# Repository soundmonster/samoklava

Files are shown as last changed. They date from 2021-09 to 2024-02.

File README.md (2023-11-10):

# samoklava
## An autogenerated split 36 key keyboard

## Disclaimer

This is an early experimental prototype. Please do not rely on the autogenerated files and double check them manually
before sending them off to a PCB fab. The author and other random strangers on the internet have been able to produce
working keyboard prototypes from this repo; this does not mean that everything will work every time.

The author(s) waive(s) responsibility for any damage or regulatory violations caused by using this software (see
license). Please consult your local regulations around radio frequencies and what's allowed for DIY projects in your
country.

left | right
-|-
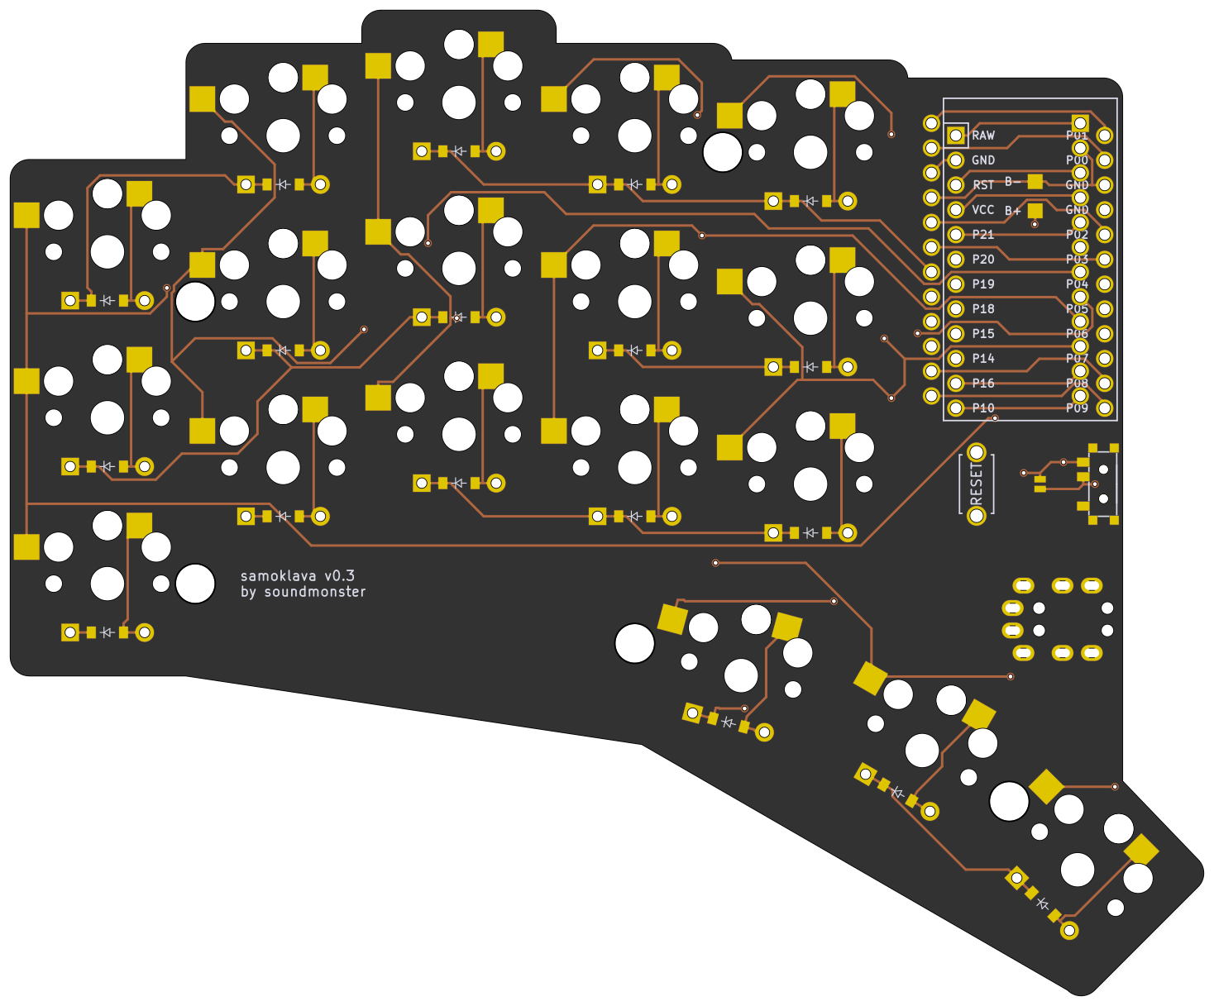
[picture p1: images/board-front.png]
left
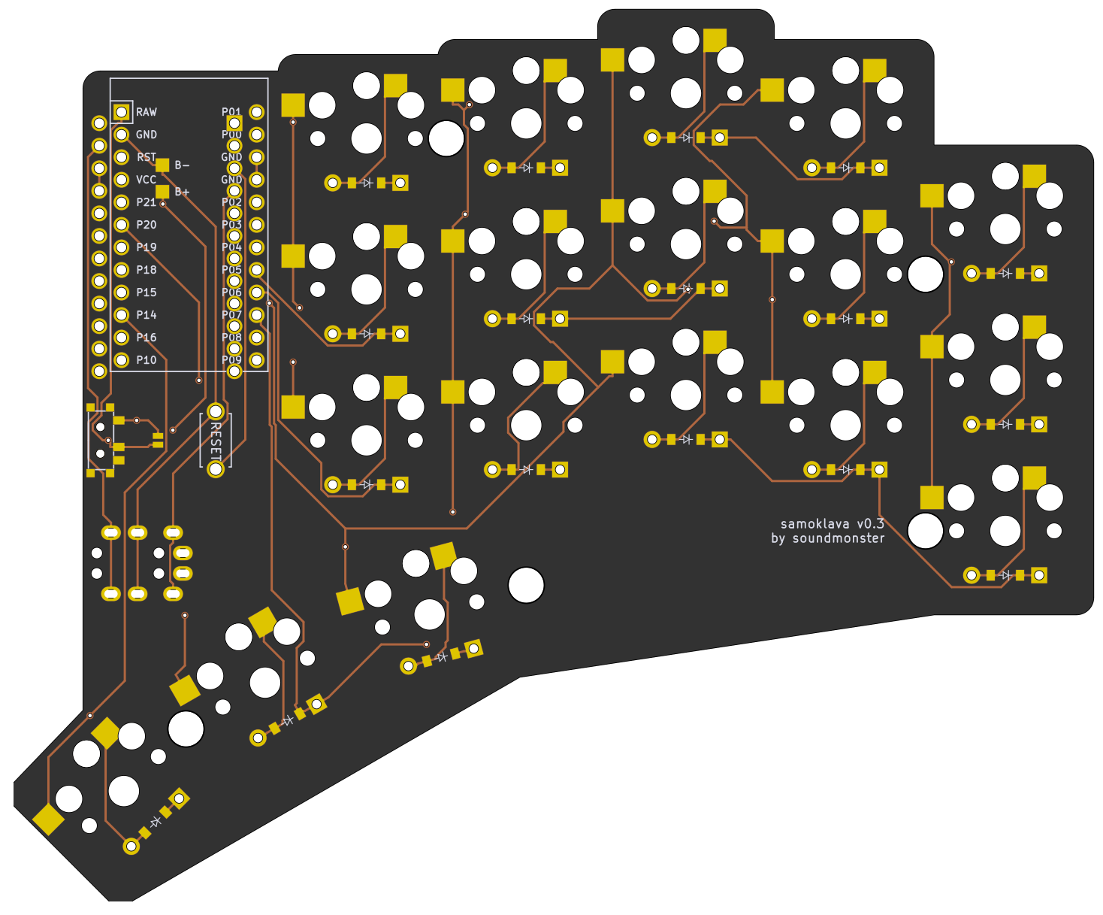
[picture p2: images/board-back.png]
right
 | 

A 5x3 split keyboard with 3 thumb keys. There is nothing unique about the keyboard layout. It's inspired by Corne and
Kyria, and has the exact number of keys needed for the [Miryoku](https://github.com/manna-harbour/miryoku) layout.

The interesting thing about this keyboard is that it's a declarative design:
* Layout is declared using [Ergogen](https://github.com/mrzealot/ergogen/). New: no fork needed!
* The build system uses Ergogen to translate YAML to a KiCad PCB and plate files for FR-4 fab or laser cutting
* uses [kicad-automation-scripts](https://github.com/productize/kicad-automation-scripts) and [FreeRouting](https://github.com/freerouting/freerouting) to **automatically route the traces on the PCB**
* uses [KiKit](https://github.com/yaqwsx/KiKit) to render PCB previews (see top of this file) and production-ready **Gerber files**

## Features

* A slider switch for battery for wireless Promicro clones (tested with nice!nano); the slider can be
  shorted with a jumper if `CONFIG_ZMK_SLEEP` is preferred.
* Wired operation with QMK should be possible but is not tested; TRRS footprints are included and routed. The pinout is
  identical with a five-column Corne sans the RGBLEDs.
* Reset switches are easily accessible. The footprints used are the same as on the Corne.

## How to

If you would like to modify this:
* fork it
* change `config.yaml` to your liking
* push your changes; the `build.yml` GitHub Workflow will pick it up, autoroute and generate Gerbers, all in a zip file.
  See https://github.com/soundmonster/samoklava/actions
* or:
  * make sure to have Docker CLI and NodeJS installed
  * run `make setup clean all`
  * check the `output` folder for KiCad PCBs and Gerbers

See the [workflow](.github/workflows/build.yml) or the [Makefile](Makefile) for more details.
See [my ZMK config](https://github.com/soundmonster/samoklava-zmk-config) for a suggested keymap.

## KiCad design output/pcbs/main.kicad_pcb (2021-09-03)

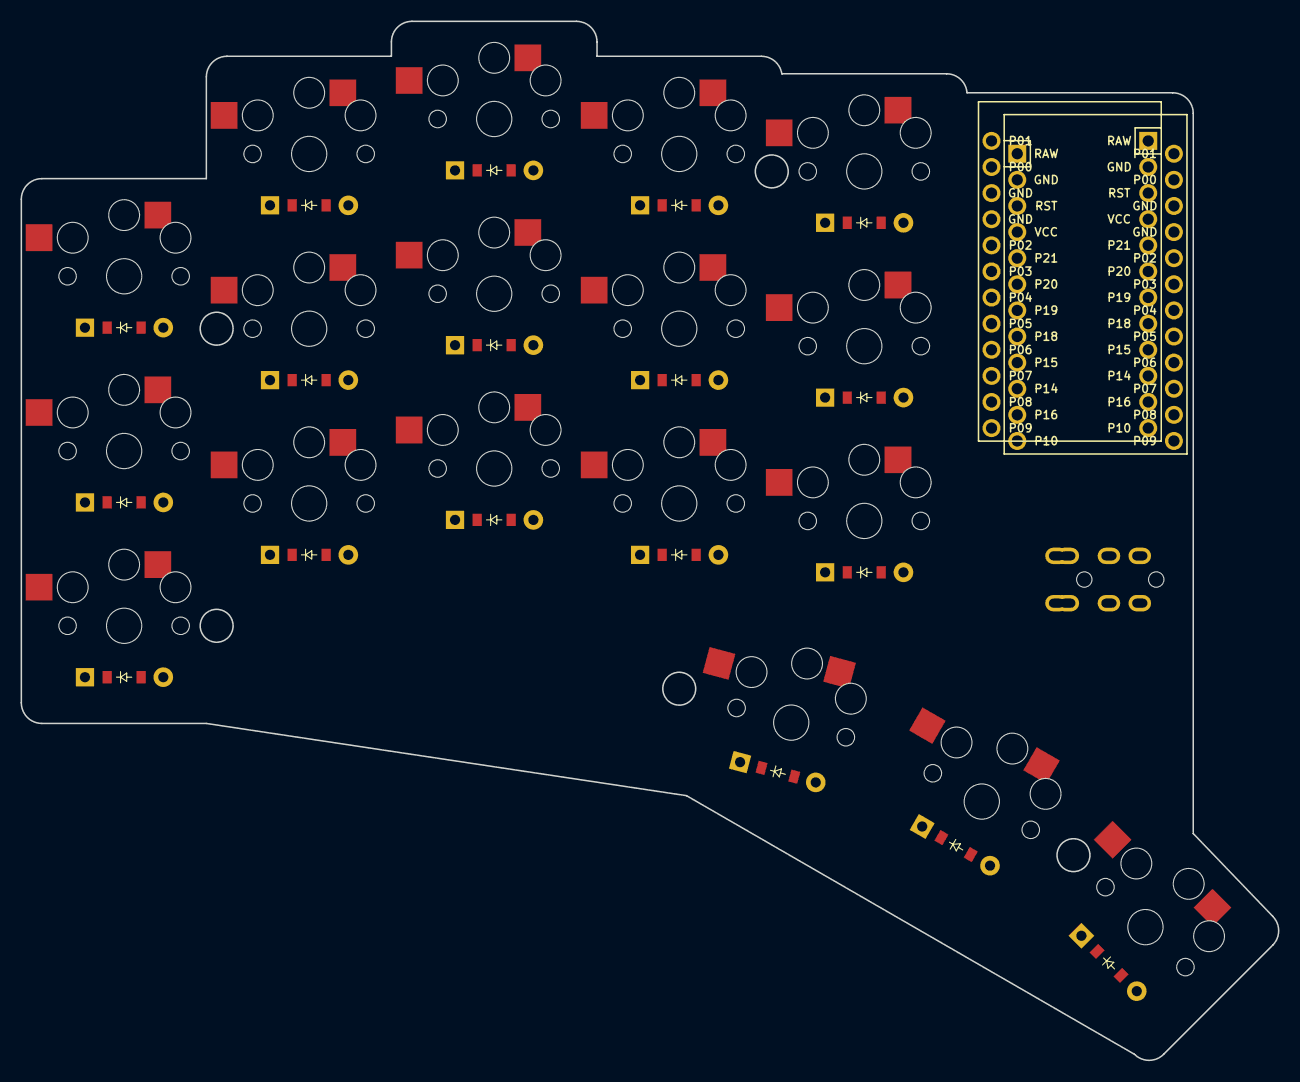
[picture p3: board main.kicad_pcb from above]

Board: 2 copper layers, 122.3 x 101.1 mm, 38 parts (0 on the bottom side), 40 nets, no tracks yet.

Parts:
D1, D2, D3, D4, D5, D6, D7, D8, D9, D10, D11, D12, D13, D14, D15, D16, D17, D18: ComboDiode
MCU1, MCU2: ProMicro
S1, S2, S3, S4, S5, S6, S7, S8, S9, S10, S11, S12, S13, S14, S15, S16, S17, S18: PG1350

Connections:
GND: MCU1.2, MCU1.15, MCU1.16, MCU2.2, MCU2.15, MCU2.16
P0: MCU1.14, MCU2.14
P1: MCU1.13, MCU2.13
P2: MCU1.17, MCU2.17
P3: MCU1.18, MCU2.18
P4: D16.1, D16.2, D17.1, D17.2, D18.1, D18.2, MCU1.19, MCU2.19
P5: D3.1, D3.2, D6.1, D6.2, D9.1, D9.2, D12.1, D12.2, D15.1, D15.2, MCU1.20, MCU2.20
P6: D2.1, D2.2, D5.1, D5.2, D8.1, D8.2, D11.1, D11.2, D14.1, D14.2, MCU1.21, MCU2.21
P7: D1.1, D1.2, D4.1, D4.2, D7.1, D7.2, D10.1, D10.2, D13.1, D13.2, MCU1.22, MCU2.22
P8: MCU1.23, MCU2.23
P9: MCU1.24, MCU2.24
P10: MCU1.12, MCU2.12
P14: MCU1.10, MCU2.10
P15: MCU1.9, MCU2.9, S13.2, S14.2, S15.2, S18.2
P16: MCU1.11, MCU2.11
P18: MCU1.8, MCU2.8, S10.2, S11.2, S12.2, S17.2
P19: MCU1.7, MCU2.7, S7.2, S8.2, S9.2, S16.2
P20: MCU1.6, MCU2.6, S4.2, S5.2, S6.2
P21: MCU1.5, MCU2.5, S1.2, S2.2, S3.2
RAW: MCU1.1, MCU2.1
RST: MCU1.3, MCU2.3
VCC: MCU1.4, MCU2.4
far_thumb: D18.1, D18.2, S18.1
home_thumb: D17.1, D17.2, S17.1
index_bottom: D10.1, D10.2, S10.1
index_home: D11.1, D11.2, S11.1
index_top: D12.1, D12.2, S12.1
inner_bottom: D13.1, D13.2, S13.1
inner_home: D14.1, D14.2, S14.1
inner_top: D15.1, D15.2, S15.1
middle_bottom: D7.1, D7.2, S7.1
middle_home: D8.1, D8.2, S8.1
middle_top: D9.1, D9.2, S9.1
near_thumb: D16.1, D16.2, S16.1
pinky_bottom: D1.1, D1.2, S1.1
pinky_home: D2.1, D2.2, S2.1
pinky_top: D3.1, D3.2, S3.1
ring_bottom: D4.1, D4.2, S4.1
ring_home: D5.1, D5.2, S5.1
ring_top: D6.1, D6.2, S6.1

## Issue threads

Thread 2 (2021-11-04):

Ensure pinout compatibility with Cradio shield in ZMK

soundmonster, 2021-11-04:
Current pinout is probably workable but not compatible with Corne and similar other keyboards. This means that the prebuilt Cradio shield from ZMK can't be used without modification. Change pinout to be identical for
- [ ] rows and columns
- [ ] TRRS

Closed 2021-11-11.

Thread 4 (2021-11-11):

Verify that the battery slider is wired up correctly

soundmonster, 2021-11-11:
Datasheet: https://datasheet.lcsc.com/lcsc/2108131530_Korean-Hroparts-Elec-K3-1296S-E1_C128955.pdf
LCSC part: https://lcsc.com/product-detail/Slide-Switches_Korean-Hroparts-Elec-K3-1296S-E1_C128955.html

soundmonster, 2021-12-11:
Yes and no. It is wired up in a way that it works: it can interrupt the battery circuit. However, the orientation is not the same on both sides: assuming the sliders are mounted on the undersides of the PCBs, the left half is _on_ when the slider is pushed _away_ from the user, and the right half is _on_ when the slider is pulled _towards_ the user. This takes getting used to.

The sliders have 3 contacts and it is possible to make them work the same on both sides, but that would require patching Ergogen.

Closed 2021-12-11.

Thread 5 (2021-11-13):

Replace big SMD reset button with standard two-pin tactile switch like on the Corne

soundmonster, 2021-11-13:

Closed 2021-11-13.

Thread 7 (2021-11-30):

Add serial number placeholders for JLC

soundmonster, 2021-11-30:
Force placement of JLC's serial number somewhere between the switches below the keycaps for PCB and top plate

Closed 2021-12-10.

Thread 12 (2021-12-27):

License of the project?

Nova38, 2021-12-27:
Good evening,

This is a excellent project! Thanks for sharing it and encouraging others to fork it. I noticed that this project didn't have license attached to it. I was wondering if you could add a open source License to the repo.

Thanks

Closed 2022-01-06.

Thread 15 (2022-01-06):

Update mounting hole locations

soundmonster, 2022-01-06:
Mounting holes are off since the update to Ergogen 3.1.0.

- [ ] Update mounting hole locations
- [ ] Update mounting hole radii
- [ ] Remove warnings from the README

soundmonster, 2022-01-06:
Looked at the wrong DXF file; closing as things are all right.

Closed 2022-01-06.

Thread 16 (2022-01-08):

Simplify - remove diodes?

mankoff, 2022-01-08:
Thanks for this project - it looks amazing.  I'm new to building keyboards so I have some newbie questions. I'm currently building my first (Ferris Sweep, choc soldered directly to the board). I'd like to customize this to to my finger locations and build one for use with QMK.

Questions -

+ [ ] I'd like to simplify this as much as possible. Is it possible to remove the diodes? I have tried commenting out that section in the YAML file, or commenting it out and changing the "choc_hotwsap" `to:` from `=column_net` to `=row_net` but neither results look right to me.

+ [ ] choc_hotswap means that I solder [these](https://boardsource.xyz/store/5eca381464caf04f83aa6482) and then just push in the switches, right? In that case, how do the switches stay in? Do I need a case for this too to hold it together? Can you advise how I might change this to solder the switches directly to the board?

mankoff, 2022-01-08:
I think for (1) I was viewing `./output/pcbs/` rather than `./output/routed_pcbs/`. I **think** just commenting that section is enough, no other changes.

mankoff, 2022-01-08:
`hotswap: false`.

Closed 2022-01-08.

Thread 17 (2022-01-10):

Diodeless version

joostwestra, 2022-01-10:
Maybe "issue" is bit of a strong term here.
But since this is a purely wireless focussed build. Would it not be better to generate it as a wireless version. With 36 keys and no trrs connection you have exactly the right number of pins to use a diodeless layout.

Shahabaz-Bagwan, 2022-02-10:
https://github.com/andrewjrae/rae-dux This is what you are looking for

joostwestra, 2022-02-18:
Yes I found that branch as well and had a chat with the branch owner. Unfortunately the auto routing does not finish on his board.

stuart-warren, 2022-05-26:
I'd like the same thing.

This one might work, I haven't actually ordered/tested yet
https://github.com/stuart-warren/samoklava/tree/36sweep

I'm not sure why the images are out of date though

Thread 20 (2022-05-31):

standoff size

stuart-warren, 2022-05-31:
Hello, I really like this project.

Sorry if this is a stupid question, I'm curious if you could provide the size of standoffs and screws that you use when building the full case

My guess is:
* 3 layers of 1.6mm, perhaps you use different?
* thickness of hotswap sockets ~1.85mm

= 6.65mm

Do I need the standoffs to go through the 3 layers, or do the screw threads go through the outer layers?

Perhaps this could be added to the README

Thanks

roubaobaozi, 2022-06-29:
The standoffs only go through the PCB, that's why the hole is larger in diameter than the screwholes for the top and bottom plates.

- Screw
- Top plate
- PCB
- Bottom plate
- Screw

The standoff height will be between the bottom face of the top plate, and the top face of the bottom plate.

HTH

stuart-warren, 2022-06-29:
Cool thanks, so:
The screws need to be long enough to go through the plate, plus a little bit and the standoffs need to be a similar size to the pcb and any components attached (excluding switches) ?

roubaobaozi, 2022-06-29:
That's right, usually you'd be looking for M2 screws 3mm long (if using 1.6mm FR4 for top & bottom plates, obviously if you decide to get 3mm laser cut acrylic you need longer screws)

And you'd be after around about an M2 standoff at 8mm tall if FR4 top & bottom plates, and MX. I dunno what height if you're going choc though, sorry.

soundmonster, 2022-08-28:
I'm using M2 x 5mm standoffs and the cheapest black M2 x ~3mm flathead screws I could find. These are obnoxiously expensive as they're marketed as "gaming SSD screws"; you're better off getting a bag from Ali Express. I've tried M2 x 4mm standoffs and they were too short for Kailh hotswap sockets for Chocs. Might work with soldered switches, though - haven't tried.

One other gotcha: there's one spot on the top plate where a flathead screw doesn't fit; I use a "regular" stainless steel round head screw there. They usually come with those mixed brass standoff packs anyway.

Closed 2022-08-28.

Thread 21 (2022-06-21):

XIO:  fatal IO error 11 (Resource temporarily unavailable) on X server ":601282374"       after 11 requests (8 known processed) with 0 events remaining.

ujl123, 2022-06-21:
i'm constantly hitting his error whenever I try to use the github action to autobuild the kicad file. I'm using the yaml file generated from https://ergogen.cache.works/ . As a test I tried using the sweep-like(minimal) yaml file as well as my own design and it all ends up with the below issue.

Please let me know if the stack below is useful

```
Run ./.github/actions/export-dsn
/usr/bin/docker run --name soundmonsterkicadautomationscriptslatest_9a3df0 --label 72882e --workdir /github/workspace --rm -e INPUT_PCB_FILE -e INPUT_DSN_FILE -e HOME -e GITHUB_JOB -e GITHUB_REF -e GITHUB_SHA -e GITHUB_REPOSITORY -e GITHUB_REPOSITORY_OWNER -e GITHUB_RUN_ID -e GITHUB_RUN_NUMBER -e GITHUB_RETENTION_DAYS -e GITHUB_RUN_ATTEMPT -e GITHUB_ACTOR -e GITHUB_WORKFLOW -e GITHUB_HEAD_REF -e GITHUB_BASE_REF -e GITHUB_EVENT_NAME -e GITHUB_SERVER_URL -e GITHUB_API_URL -e GITHUB_GRAPHQL_URL -e GITHUB_REF_NAME -e GITHUB_REF_PROTECTED -e GITHUB_REF_TYPE -e GITHUB_WORKSPACE -e GITHUB_ACTION -e GITHUB_EVENT_PATH -e GITHUB_ACTION_REPOSITORY -e GITHUB_ACTION_REF -e GITHUB_PATH -e GITHUB_ENV -e GITHUB_STEP_SUMMARY -e RUNNER_OS -e RUNNER_ARCH -e RUNNER_NAME -e RUNNER_TOOL_CACHE -e RUNNER_TEMP -e RUNNER_WORKSPACE -e ACTIONS_RUNTIME_URL -e ACTIONS_RUNTIME_TOKEN -e ACTIONS_CACHE_URL -e GITHUB_ACTIONS=true -e CI=true --entrypoint "/bin/sh" -v "/var/run/docker.sock":"/var/run/docker.sock" -v "/home/runner/work/_temp/_github_home":"/github/home" -v "/home/runner/work/_temp/_github_workflow":"/github/workflow" -v "/home/runner/work/_temp/_runner_file_commands":"/github/file_commands" -v "/home/runner/work/samoklava/samoklava":"/github/workspace" soundmonster/kicad-automation-scripts:latest  "-c" "mkdir -p $HOME/.config/kicad ;
cp /root/.config/kicad/* $HOME/.config/kicad ;
/usr/lib/python2.7/dist-packages/kicad-automation/pcbnew_automation/export_dsn.py output/pcbs/board.kicad_pcb output/pcbs/board.dsn
"
Unable to find image 'soundmonster/kicad-automation-scripts:latest' locally
latest: Pulling from soundmonster/kicad-automation-scripts
124c757242f8: Pulling fs layer
9d866f8bde2a: Pulling fs layer
fa3f2f277e67: Pulling fs layer
398d32b153e8: Pulling fs layer
afde35469481: Pulling fs layer
84c890a4c945: Pulling fs layer
c2d270e31686: Pulling fs layer
44b62cfa4727: Pulling fs layer
ee39436fdbef: Pulling fs layer
cd840ecddeb7: Pulling fs layer
ae65f875717a: Pulling fs layer
398d32b153e8: Waiting
afde35469481: Waiting
84c890a4c945: Waiting
c2d270e31686: Waiting
44b62cfa4727: Waiting
ee39436fdbef: Waiting
cd840ecddeb7: Waiting
ae65f875717a: Waiting
9d866f8bde2a: Verifying Checksum
9d866f8bde2a: Download complete
124c757242f8: Verifying Checksum
124c757242f8: Download complete
fa3f2f277e67: Verifying Checksum
fa3f2f277e67: Download complete
398d32b153e8: Verifying Checksum
398d32b153e8: Download complete
84c890a4c945: Download complete
afde35469481: Verifying Checksum
afde35469481: Download complete
44b62cfa4727: Verifying Checksum
44b62cfa4727: Download complete
cd840ecddeb7: Verifying Checksum
cd840ecddeb7: Download complete
124c757242f8: Pull complete
ae65f875717a: Verifying Checksum
ae65f875717a: Download complete
9d866f8bde2a: Pull complete
fa3f2f277e67: Pull complete
398d32b153e8: Pull complete
afde35469481: Pull complete
84c890a4c945: Pull complete
c2d270e31686: Verifying Checksum
c2d270e31686: Download complete
ee39436fdbef: Verifying Checksum
ee39436fdbef: Download complete
c2d270e31686: Pull complete
44b62cfa4727: Pull complete
ee39436fdbef: Pull complete
cd840ecddeb7: Pull complete
ae65f875717a: Pull complete
Digest: sha256:6aef0d06c62b0e9859b1f3c869f329bf7b156fc360e0076c687827ca62e57d27
Status: Downloaded newer image for soundmonster/kicad-automation-scripts:latest
INFO:util.ui_automation:Waiting for pcbnew window...
XIO:  fatal IO error 11 (Resource temporarily unavailable) on X server ":601282374"
      after 11 requests (8 known processed) with 0 events remaining.
Traceback (most recent call last):
  File "/usr/lib/python2.7/dist-packages/kicad-automation/pcbnew_automation/export_dsn.py", line 100, in <module>
    export_result = run_export(args.kicad_pcb_file, args.output_file, args.record)
  File "/usr/lib/python2.7/dist-packages/kicad-automation/pcbnew_automation/export_dsn.py", line 64, in run_export
    window = wait_for_window('pcbnew', 'Pcbnew', 10, False)
  File "/usr/lib/python2.7/dist-packages/kicad-automation/util/ui_automation.py", line 99, in wait_for_window
    raise RuntimeError('Timed out waiting for %s window' % name)
RuntimeError: Timed out waiting for pcbnew window
```

thoni56, 2022-07-17:
I get this too. This [Stackoverflow answer](https://stackoverflow.com/a/13755424/204658) might indicate where the root cause is, but that indicates that the docker image contains software that handles its sockets wrong. But since I don't know what that image actually does, I get no further. Which is a pity...

thoni56, 2022-07-17:
I tried to run the same docker command locally but it also failed in exactly the same way, which confirms my suspition about the image. I guess we'll have to wait for @soundmonster to have a look at this.

toniz4, 2022-08-02:
> I get this too. ~This [Stackoverflow answer](https://stackoverflow.com/a/13755424/204658) might indicate where the root cause is, but that indicates that the docker image contains software that handles its sockets wrong. But since I don't know what that image actually does, I get no further.~

A fix is running the build script without the X11 server running, either on a tty or (probably) wayland.

> I know think that it is the `ergogen` error in #22 that is causing this error.
>
> Which is a pity...

Probably not an issue, soundmonter uses a specific branch of his ergogen fork, that he implements that feature. If you try to run the yaml file in ergogen ui or the default ergogen, it will fail to export a pcb, but on ergogen ui you can set it to update on change and just use it as a preview for the drawings.

soundmonster, 2022-08-28:
The Makefile and also the GH workflow make (strong) assumptions about how things are named. Probably both have to be adjusted so they work together. The GH workflow assumes:
* the main PCB with routes and footprints exists and is called `board`
* there is a top and bottom plates also output as PCBs (without footprints or traces, just nicely cut FR4) that are called `top_plate` and `bottom_plate`.

I guess a good starting point would be if you could point me to your fork so I could have a look. Possible solutions could be one or several of the following:
* rename the main PCB to `board` in Ergogen YAML
* make sure to use my fork of Ergogen in `package.json` if you're generating top/bottom plates as PCBs
* rename the files in the GH workflow to suit what's in your YAML
* remove top/bottom plate generation from the workflow if you don't need them at all, or plan to use another Ergogen fork.

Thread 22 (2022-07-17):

Error: Unexpected key "include_keys" within field "pcbs.top_plate"!

thoni56, 2022-07-17:
I ran the `build.sh` script locally (with `ergogen` locally). Unfortunately it failed too (#22) with

```
> ergogen samoklava.yaml

Ergogen v3.1.2 CLI

Interpreting format: YAML
Preprocessing input...
Calculating variables...
Parsing points...
Generating outlines...
Extruding cases...
Scaffolding PCBs...
Error: Unexpected key "include_keys" within field "pcbs.top_plate"!
    at exports.assert (C:\Users\Thomas\AppData\Roaming\npm\node_modules\ergogen\src\as
sert.js:12:15)
    at Object.exports.unexpected (C:\Users\Thomas\AppData\Roaming\npm\node_modules\erg
ogen\src\assert.js:35:9)
    at Object.exports.parse (C:\Users\Thomas\AppData\Roaming\npm\node_modules\ergogen\
src\pcbs.js:243:11)
    at Object.process (C:\Users\Thomas\AppData\Roaming\npm\node_modules\ergogen\src\er
gogen.js:84:27)
    at C:\Users\Thomas\AppData\Roaming\npm\node_modules\ergogen\src\cli.js:58:29
    at Object.<anonymous> (C:\Users\Thomas\AppData\Roaming\npm\node_modules\ergogen\sr
c\cli.js:126:3)
```

This is also evident when pasting the yaml into webversion of `ergogen`.

Perhaps this is what's causing #21 but we're not seeing the ergogen error. The build script finished with the same XIO error...

thoni56, 2022-07-17:
This is with `ergogen` 3.1.2, but I don't get this error with 3.1.0 which is in the repos `package.json`, so it is probably not causing #21.

soundmonster, 2022-08-28:
How did you install Ergogen? I would recommend using Samoklava's `Makefile`:

* `make setup` will install my Ergogen fork
* `make clean all` will generate and autoroute the board; requires Docker or Podman

thoni56, 2022-08-28:
Thanks, yes, I learned that Samoklava has patched Ergogen. Not sufficiently visible there I would say. Thanks for reminding me to close this.

Closed 2022-08-28.

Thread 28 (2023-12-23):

pcbdraw fails when running Docker locally

TildeWill, 2023-12-23:
I'm on OSX, running the repo from a clean checkout of what's currently main HEAD d5f78f63a1e78360cb03efc049de3ee2ea600c02

When I get to this step of `make setup clean all`
```
 docker run -w /board -v /Users/readwl/workspace/keyboards/magellan:/board --rm yaqwsx/kikit:v0.7 pcbdraw --style builtin:oshpark-afterdark.json output/routed_pcbs/board.kicad_pcb output/routed_pcbs/board-front.png
```
I get this output/error:
```
Traceback (most recent call last):
  File "/usr/local/bin/pcbdraw", line 8, in <module>
    sys.exit(main())
  File "/usr/local/lib/python3.8/dist-packages/pcbdraw/pcbdraw.py", line 793, in main
    board_cont.append(get_board_substrate(board, style, not args.no_drillholes, args.back))
  File "/usr/local/lib/python3.8/dist-packages/pcbdraw/pcbdraw.py", line 445, in get_board_substrate
    process(container, f, os.path.join(tmp, svg_file), colors, boardsize)
  File "/usr/local/lib/python3.8/dist-packages/pcbdraw/pcbdraw.py", line 329, in process_board_substrate_base
    clipPath.append(get_board_polygon(extract_svg_content(read_svg_unique(source))))
  File "/usr/local/lib/python3.8/dist-packages/pcbdraw/pcbdraw.py", line 277, in get_board_polygon
    elements.append(SvgPathItem(svg_element.attrib["d"]))
  File "/usr/local/lib/python3.8/dist-packages/pcbdraw/pcbdraw.py", line 52, in __init__
    raise SyntaxError("Only paths with absolute position are supported")
SyntaxError: Only paths with absolute position are supported
```

[Researching this error seems to point to an old version of kikit](https://github.com/yaqwsx/PcbDraw/issues/62), but upgrading the image from 0.7 to 1.x seems to do away with the pcbdraw command, so I'm at a loss for what to do. I see that the Github action passed pretty recently so I assume this is something about my environment. Any help would be appreciated!

hedefalk, 2024-01-24:
@TildeWill

I'm doing this in my fork:

```Makefile
kikit ?= yaqwsx/kikit:v1.3.0

…
output/routed_pcbs/%-front.png: output/routed_pcbs/%.kicad_pcb
	mkdir -p $(shell dirname $@)
	${container_cmd} run --entrypoint pcbdraw ${container_args} ${kikit} plot --style oshpark-afterdark.json $< $@

output/routed_pcbs/%-back.png: output/routed_pcbs/%.kicad_pcb
	mkdir -p $(shell dirname $@)
	${container_cmd} run --entrypoint pcbdraw ${container_args} ${kikit} plot --side back --style oshpark-afterdark.json $< $@
```

TildeWill, 2024-01-25:
Thanks @hedefalk! What changes did you make to the gerbers step that also references kitkit? I get this error:

`Board 'output/routed_pcbs/<MY BOARD NAME>.kicad_pcb' has no project, cannot read DRC exclusions`

TildeWill, 2024-01-25:
Disregard, I see there's [already a PR](https://github.com/soundmonster/samoklava/pull/29) that answers my question

Closed 2024-01-25.

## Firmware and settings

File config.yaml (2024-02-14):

meta:
  engine: 4.0.4
  name: samoklava
  version: 0.3
  author: soundmonster
  url: https://github.com/soundmonster/samoklava
units:
  kx: cx
  ky: cy
  px: 2
  py: 2
points:
  key:
    footprints:
      choc_hotswap:
        type: choc
        params:
          hotswap: true
          reverse: true
          keycaps: true
        nets:
          from: =colrow
          to: =column_net
      diode:
        type: diode
        nets:
          from: =colrow
          to: =row_net
        anchor:
          shift: [0, -5]
  zones:
    matrix:
      key.padding: ky
      columns:
        pinky:
          key:
            stagger: 0 ky
            spread: kx
            column_net: col_pinky
        ring:
          key:
            stagger: 0.7 ky
            spread: kx
            column_net: col_ring
        middle:
          key:
            stagger: 0.2 ky
            spread: kx
            column_net: col_middle
        index:
          key:
            stagger: -0.2 ky
            spread: kx
            column_net: col_index
        inner:
          key:
            stagger: -0.1 ky
            spread: kx
            column_net: col_inner
      rows:
        bottom:
          row_net: row_bottom
        home:
          row_net: row_home
        top:
          row_net: row_top
    thumbfan:
      anchor:
        ref: matrix_inner_bottom
        shift: [-0.5 kx, -1 ky]
      columns:
        near:
          key:
            spread: kx
            splay: -15
            origin: [-0.5 kx, -0.5 ky]
            column_net: col_middle
        home:
          key:
            spread: kx
            splay: -15
            origin: [-0.5 kx, -0.5 ky]
            column_net: col_index
        far:
          key:
            spread: kx
            splay: -15
            origin: [-0.5 kx, -0.5 ky]
            column_net: col_inner
      rows:
        thumb:
          row_net: row_thumb
outlines:
  # board dimensions according to JLCPCB: 122.28 mm x 101.05 mm
  raw:
    - what: rectangle
      where: true
      asym: source
      size: [kx + px, ky + py]
      corner: px
  thumbfan_glue:
    - what: polygon
      points:
        - ref: matrix_inner_bottom
          shift: [0.5 kx + 0.5px, -0.5 ky + 0.5 py]
        - ref: thumbfan_far_thumb
          shift: [0.5 kx - 0.5px, 0.5 ky + 0.5 py]
        - ref: thumbfan_far_thumb
          shift: [0.5 kx - 0.5px, -0.5 ky - 0.5 py]
        - ref: thumbfan_near_thumb
          shift: [-0.5 kx + 0.5 px, -0.5 ky - 0.5 py]
        - ref: matrix_pinky_bottom
          shift: [0.5 kx - 0.5 py, -0.5 ky - 0.5 py]
        - ref: matrix_pinky_home
        - ref: matrix_inner_home
  patch_outer:
    - what: polygon
      points:
        - ref: matrix_ring_top
        - ref: matrix_ring_bottom
        - ref: matrix_pinky_bottom
          shift: [-0.5 (kx + px), 0]
        - ref: matrix_pinky_top
          shift: [-0.5 (kx + px), 0]
  patch_inner:
    - what: polygon
      points:
        - ref: matrix_inner_top
          shift: [0.5 (kx + px), 0]
        - ref: matrix_inner_bottom
          shift: [0.5 (kx + px), 0]
        - ref: matrix_index_bottom
        - ref: matrix_index_top
  controller_area:
    - what: rectangle
      where:
        - ref: matrix_inner_top
          # re-tranalte to new anchor position
          shift: [32/2 + 0 kx, 76.5/2 - 4.05 ky]
      size: [32, 76.5]
      corner: px
  switches:
    - what: rectangle
      where: true
      asym: source
      size: 14
  keycaps:
    - what: rectangle 
      where: true
      asym: source
      size: [kx, ky] 
      corner: 1
  keywell:
    - "raw"
    - "+patch_inner"
    - "+patch_outer"
    - "+thumbfan_glue"
  base_outline:
    - "keywell"
    - "+controller_area"
  screw_holes:
    top_left:
      what: circle
      where:
        - ref: matrix_ring_home
          shift: [-0.5 kx, 0 ky]
      radius: 1.05
    bottom_left:
      what: circle
      where:
        - ref: matrix_pinky_bottom
          shift: [0.5 kx, 0]
      radius: 1.05
    top_right:
      what: circle
      where:
        - ref: matrix_inner_top
          shift: [-0.5 kx, 0]
      radius: 1.05
    palm:
      what: circle
      where:
        - ref: matrix_index_bottom
          shift: [0, -1.06 ky]
      radius: 1.05
    thumb:
      what: circle
      where:
        - ref: thumbfan_far_thumb
          shift: [-0.55 kx, 0]
      radius: 1.05
  mounting_holes:
    $extends: outlines.screw_holes
    top_left:
      radius: 2.05
    bottom_left:
      radius: 2.05
    top_right:
      radius: 2.05
    palm:
      radius: 2.05
    thumb:
      radius: 2.05
  bottom_outline:
    - "base_outline"
    # TODO use footprints with pad + via reinforcement as mounting holes
    - "-screw_holes"
  plate:
    - "keywell"
    - "-switches"
    - "-screw_holes"
  pcb:
    - "base_outline"
    # TODO use footprints with pad + via reinforcement as mounting holes
    - "-mounting_holes"
pcbs:
  top_plate:
    outlines:
      edge:
        outline: plate
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

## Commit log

2021-09-03 Add output
    [base_outline.dxf, bottom_outline.dxf, controller_area.dxf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]
2021-09-10 First working version
    [main-routed.kicad_pcb, main.dsn]
2021-09-10 Some updates, not ready for publishing yet
    [main-routed-CmtUser.gbr, main-routed-CuBottom.gbr, main-routed-CuTop.gbr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]
2021-09-16 Wip Makefile
    [bottom_outline.dxf, bottom_plate.kicad_pcb, controller_area.yaml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]
2021-09-18 First working version of Makefile
    [board-CmtUser.gbr, board-CuBottom.gbr, board-CuTop.gbr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]
2021-10-13 A probably working version
    [board-CmtUser.gbr, board-CuBottom.gbr, board-CuTop.gbr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]
2021-10-14 Fix nested gerber dirs
2021-10-14 Make mounting holes a bit larger
2021-10-14 Add output files
    [board-CmtUser.gbr, board-CuBottom.gbr, board-CuTop.gbr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]
2021-11-11 Fix pinout (#3)
    * Fix pin compatibility with Corne
    * Add battery pins for nice!nano
    * Add reset microswitch
    * Fix TRRS reversibility
    * Add a slider to shut off battery
    [board-CmtUser.gbr, board-CuBottom.gbr, board-CuTop.gbr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]
2021-11-13 Use a better reset button footprint (#6)
    [board-CmtUser.gbr, board-CuBottom.gbr, board-CuTop.gbr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]
2021-11-13 Use dark PCB style; remove custom style file
2021-12-10 Add autorouting via GitHub Workflow (#8)
    [base_outline.dxf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]
2021-12-10 Add an order number placeholder on the top plate (#9)
2021-12-10 Upload board images separately
2022-01-06 Update board renders
2022-08-28 Use 24-pin promicro footprint; unifomly align sliders (#23)
2023-08-21 Upgrade to Ergogen v4 (#25)
    * Upgrade to Ergogen v4 and its new positioning / offset rules
    * Make Samoklava a "bundle" that includes all of its custom footprints
2024-02-10 Fix pcbdraw/kikit calls (#29)
    [config.yaml]
2024-02-14 Put Promicro silk prints on the right sides
